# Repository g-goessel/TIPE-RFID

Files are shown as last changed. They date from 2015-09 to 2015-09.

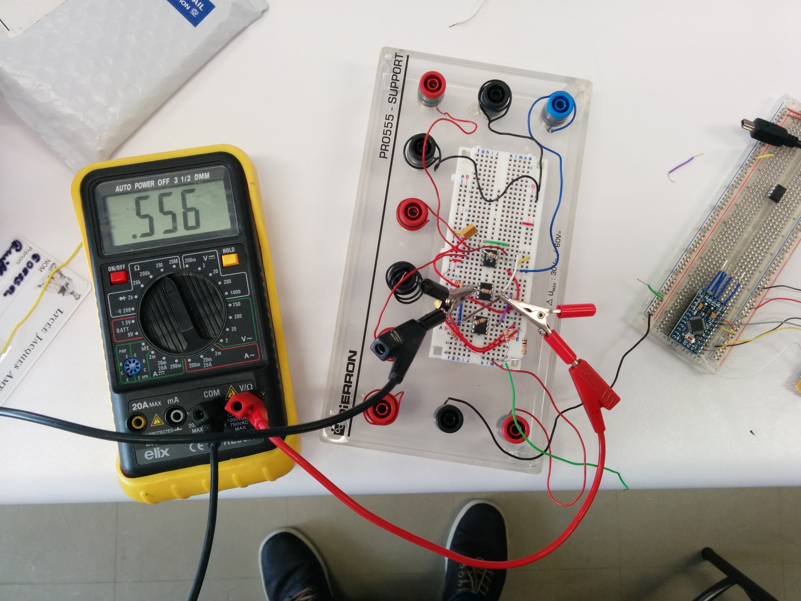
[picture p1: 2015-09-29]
Photos/IMG_20150519_115124.jpg

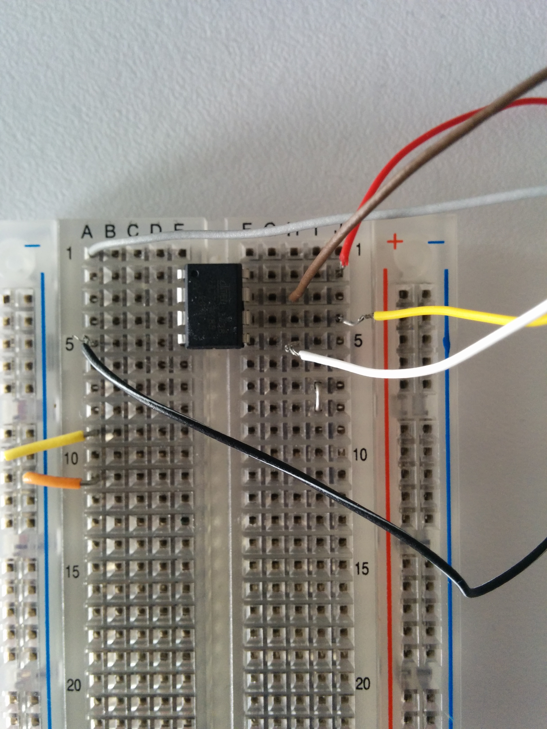
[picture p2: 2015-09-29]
Photos/IMG_20150522_102819.jpg

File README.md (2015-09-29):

# TIPE
Mon TIPE présenté en 2015

# Sujet
La RFID :
Comment les informations d'une carte RFID sont-elles réparties dans le message transmis au lecteur ?

# Schéma électronique
Il faut utiliser le logiciel Fritzing

# Aquisitions de signal
Logiciel Latis Pro (http://eurosmart.biz/logiciels/8-latis-pro.html)

# License
This Source Code Form is subject to the terms of the Mozilla Public
License, v. 2.0. If a copy of the MPL was not distributed with this
file, You can obtain one at http://mozilla.org/MPL/2.0/.

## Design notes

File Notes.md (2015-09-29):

# Mesure de champ électromagnétique à proximité d'un capteur

Calibre 5-400 kHz
A distance : 3.4 Vm
A proximité : 51 Vm

# Detection d'enveloppe VS détection asynchrone

Enveloppe : + simple

Asynchrone : + précis

# Analyse du protocole

On reconnait une répétition des signaux
Mais il ne smeble pas y avoir de signaux de début ou de fin (pas de temps de pause caractéristiques entre 2 répétitions)

protocole fdx-b:
http://www.priority1design.com.au/fdx-b_animal_identification_protocol.html

encoding :
http://www.priority1design.com.au/em4100_protocol.html

# période du signal

pour une fréquence de 134kHz on a une horloge de 237µs pour le signal

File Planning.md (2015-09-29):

# 3/10 :
Première expérience avec 2 bobines, un GDF réglé en sinusoïde à 125kHz
+ Impossible de lire un signal à l'oscillo
+ On remarque des variations dans le signal recu, il est un peu brouillé (car le signal recu n'est pas périodique)
+ Tentative avec un multiplicateur mais pas de resultats

Pour la semaine suivante : il va falloir mettre en place un système pour récupérer l'enveloppe

# 17/10 :
Tentative d'obtenir un signal clair
Succès d'obtention du signal modulant = message de la carte

# 14/11 :
Obtention des premiers signaux
Enregistrement de plusieurs cartes
Début de la reconnaissance du protocole

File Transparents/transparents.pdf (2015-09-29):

# La RFID :

## Comment les informations d'une carte RFID sont-elles réparties dans le message transmis au lecteur ?

# I – Introduction à la RFID et détails de ma carte

## - Utilisations courantes de la RFID - Détermination du protocole de ma carte

# II – Mise en place d'un lecteur automatique

## - Un circuit électronique pour lire - Un programme pour décoder

# Dénominations usuelles :

Nom commercial | Caractéristiques | Utilisation
NFC | 13,56 MHz | Paiement sans contact
| ≈ 1 cm | Cartes de transport
| ≈ 10 ko/s | authentification
| 125 kHz | Suivi de paquets
| ≈ 1 cm | Badges de paiement
| 100 o/s | Identification des animaux
| 8,2 MHz | Anti-vol

### Notes : - Différentes fréquences : pénétration / vitesse / disponibilité - Communication uni/bi-directionelle - Programmation à distance

# Analyse de ma carte :

## - Mesure approximative - Approche plus précise

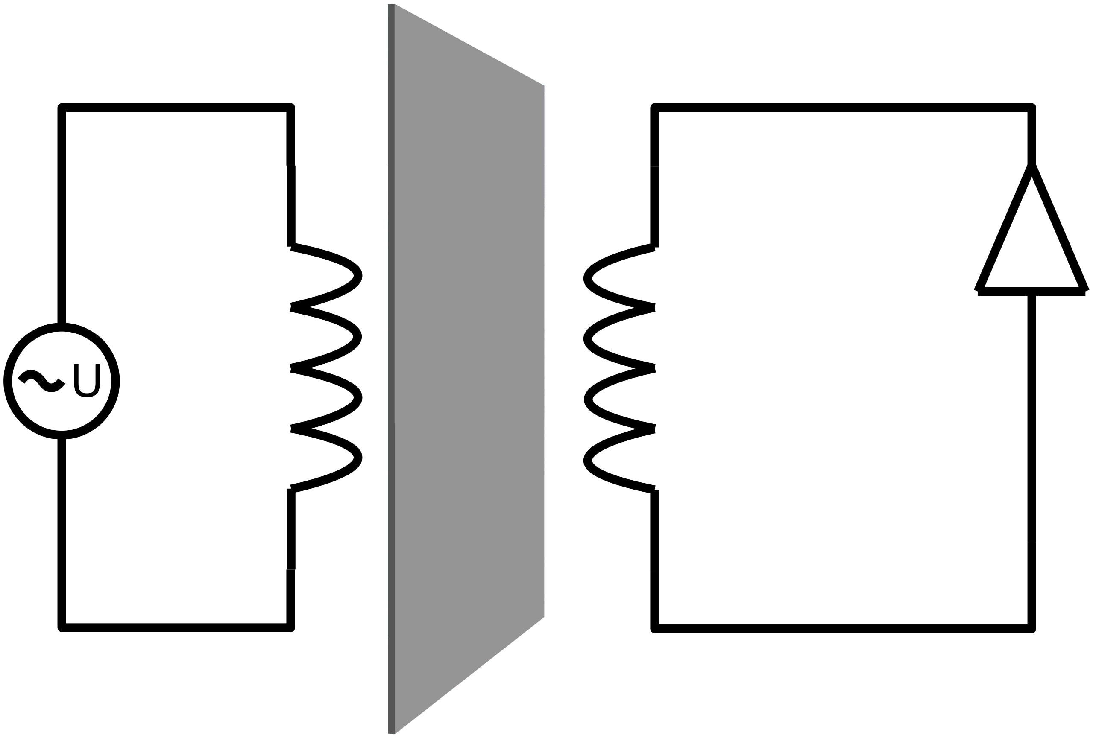
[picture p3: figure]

à 134kHZ :

≈ 100 mv

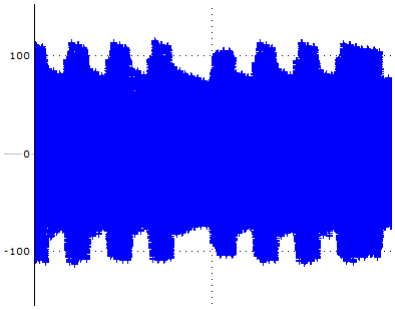
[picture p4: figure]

≈ 5 ms

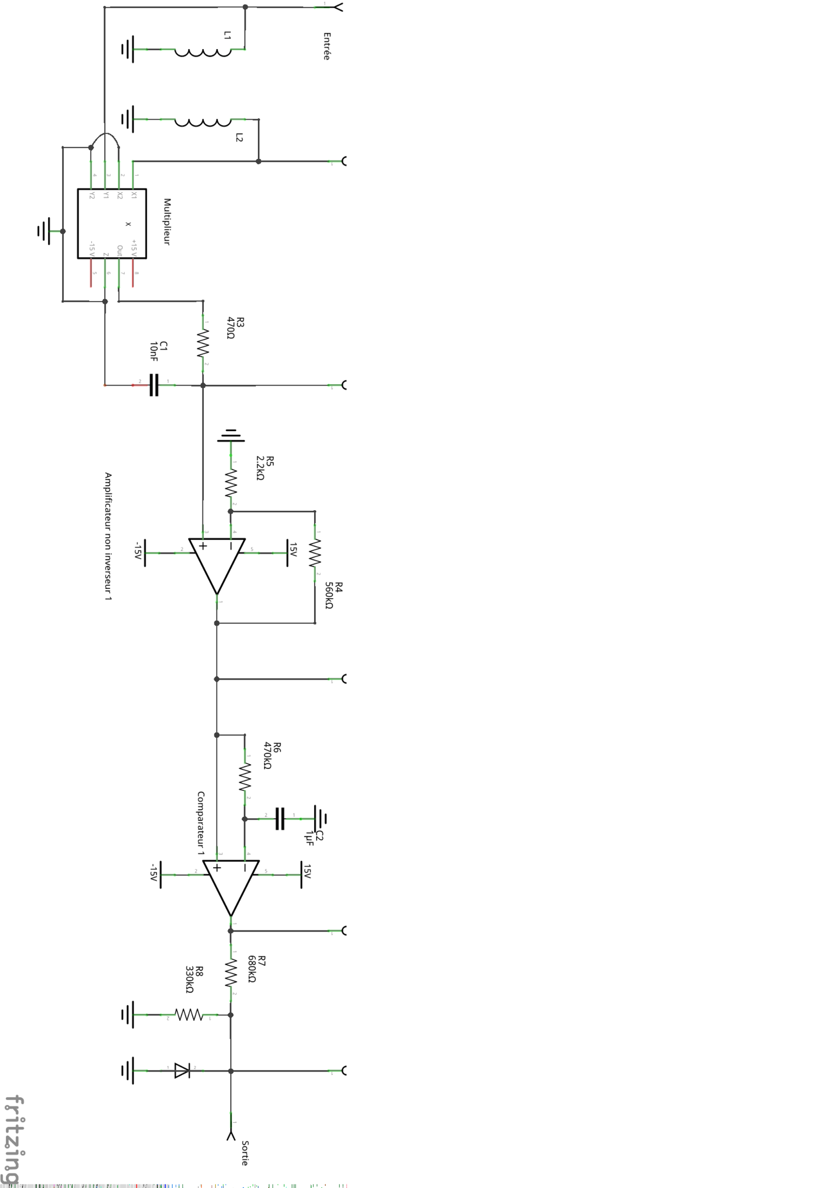
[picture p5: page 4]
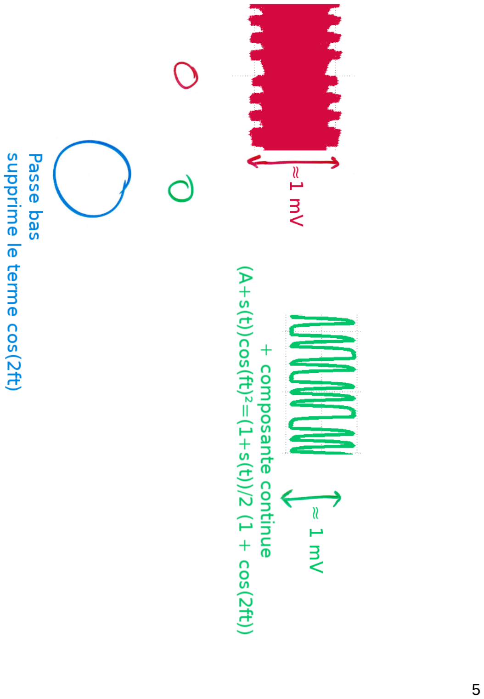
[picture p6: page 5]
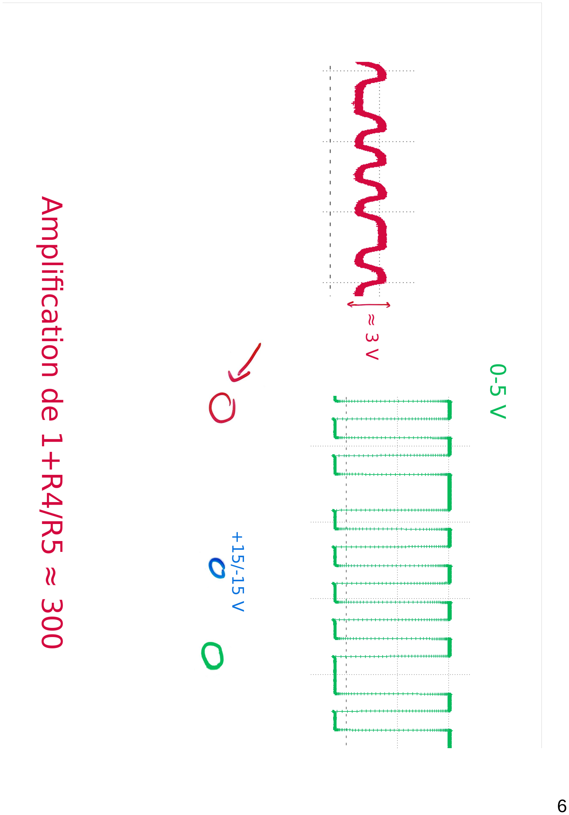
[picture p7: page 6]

# Détails du protocole de ma carte :

## - Codage en Manchester

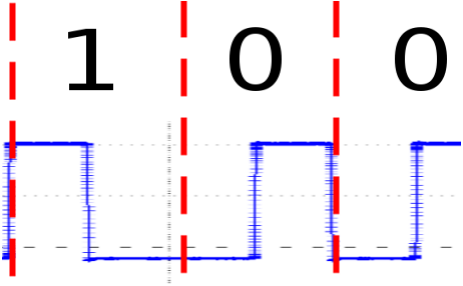
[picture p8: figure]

## Remarque : une impulsion longue indique un changement de bit

# Analyse de ma carte :

## - Première idée On effectue UNE seule mesure par période

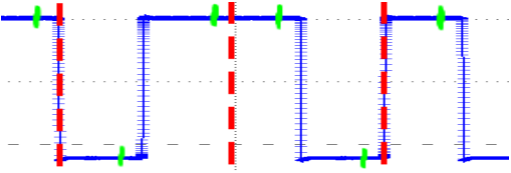
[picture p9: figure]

## Échec car peu précis

# Analyse de ma carte :

## - Seconde idée

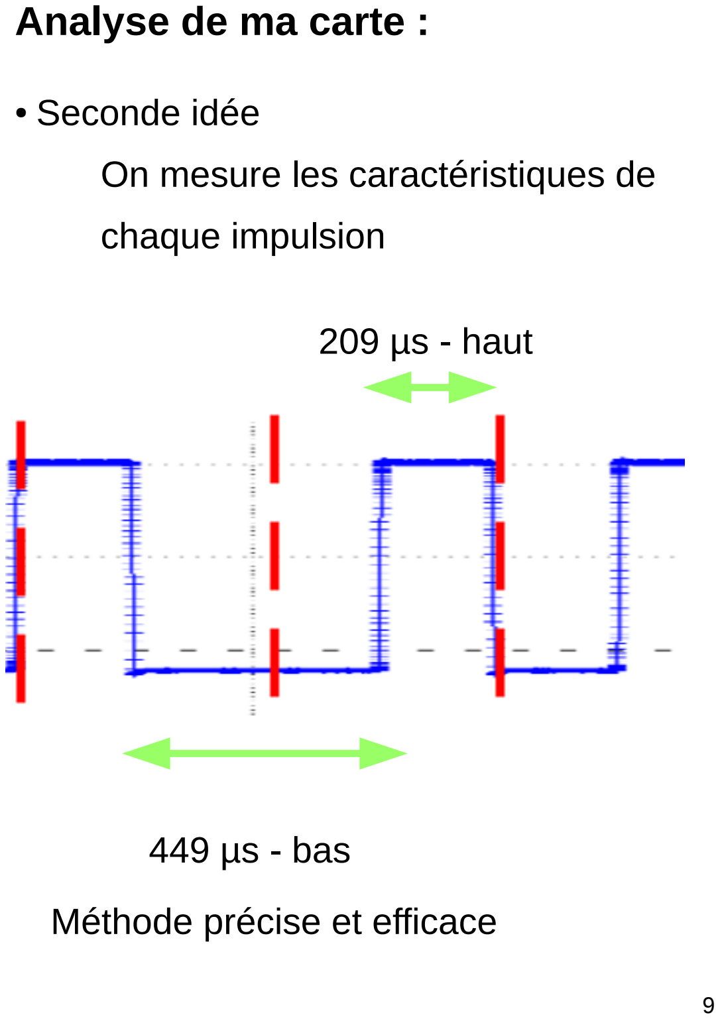
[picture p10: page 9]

## On mesure les caractéristiques de chaque impulsion

## 449 µs - bas

## 209 µs - haut

## Méthode précise et efficace

# Décodage par ordinateur :

## - Détail du protocole EM4100 (EM Microelectronic)

1 1 1 1 1 1 1 1 1
0 0 0 0 | 0
1 0 1 0 | 0
0 0 0 0 | 0
0 0 1 1 | 0
0 0 0 0 | 0
0 0 0 0 | 0
0 0 0 0 | 0
0 0 0 1 | 1
1 1 0 0 | 0
0 0 1 1 | 0
0 1 1 1 | 0

# Décodage par ordinateur :

## - Détail du programme 1) Distinguer impulsions longues et courtes

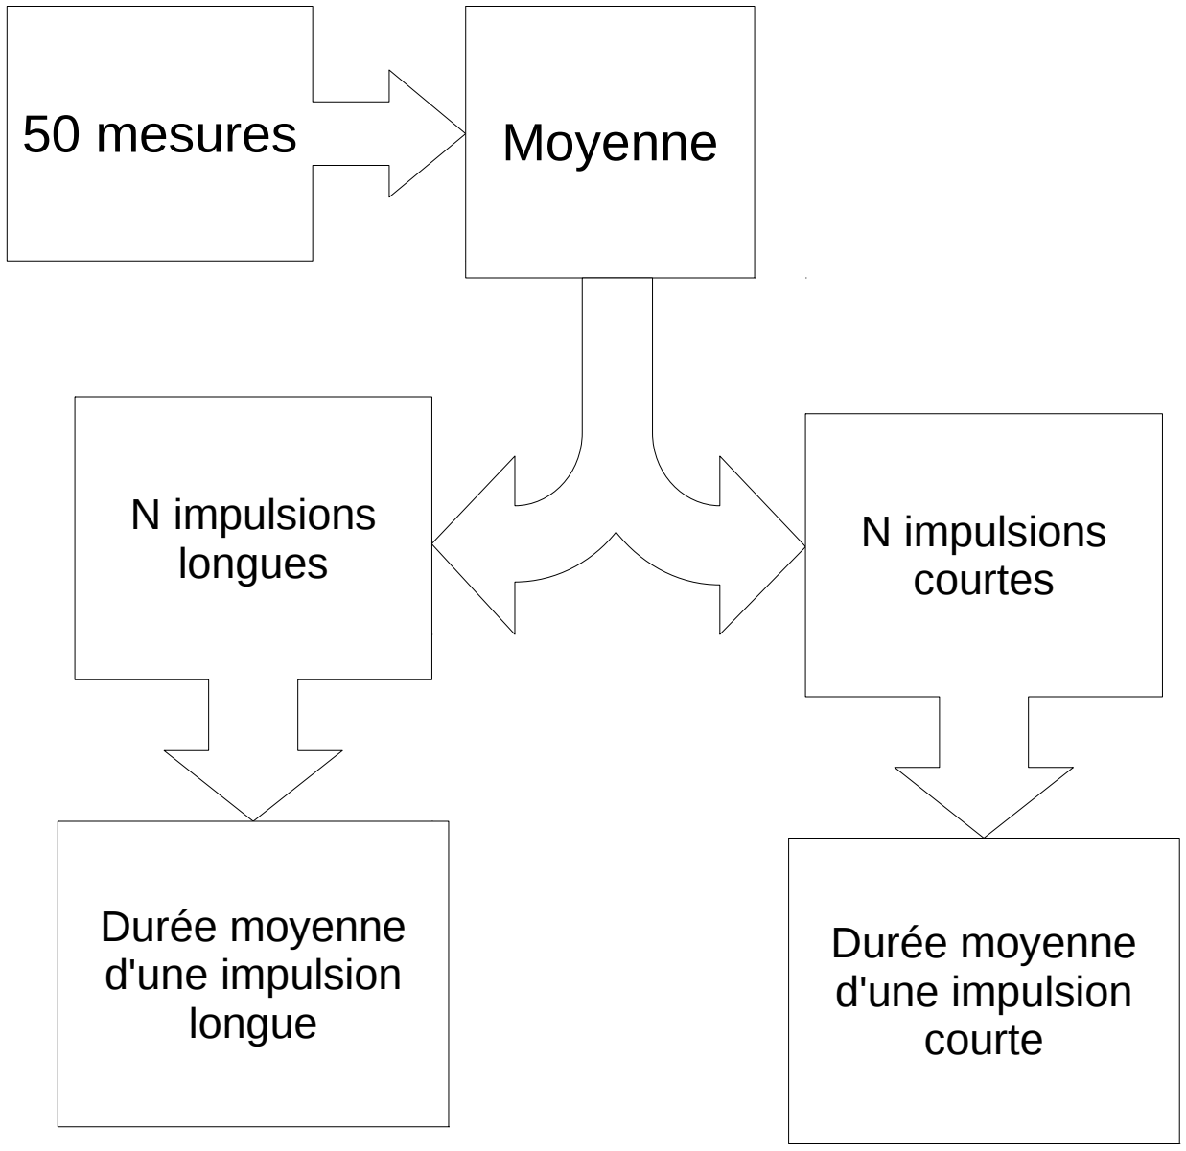
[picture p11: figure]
50 mesures; Moyenne; N impulsions longues; N impulsions courtes; Durée moyenne d'une impulsion longue; Durée moyenne d'une impulsion courte

### Ensuite on compare à la moyenne des deux durées

# Décodage par ordinateur :

## 2) Reconstituer les bits par récurrence a) Initialisation

0 1

# Décodage par ordinateur :

## b) Hérédité Cas ou le bit n est 0

bit n = 0 | bit n+1 = 1
bit n = 0 | bit n+1 = bit n

Impulsion longue

Impulsion courte

# Décodage par ordinateur :

## 3) Reconstituer le message

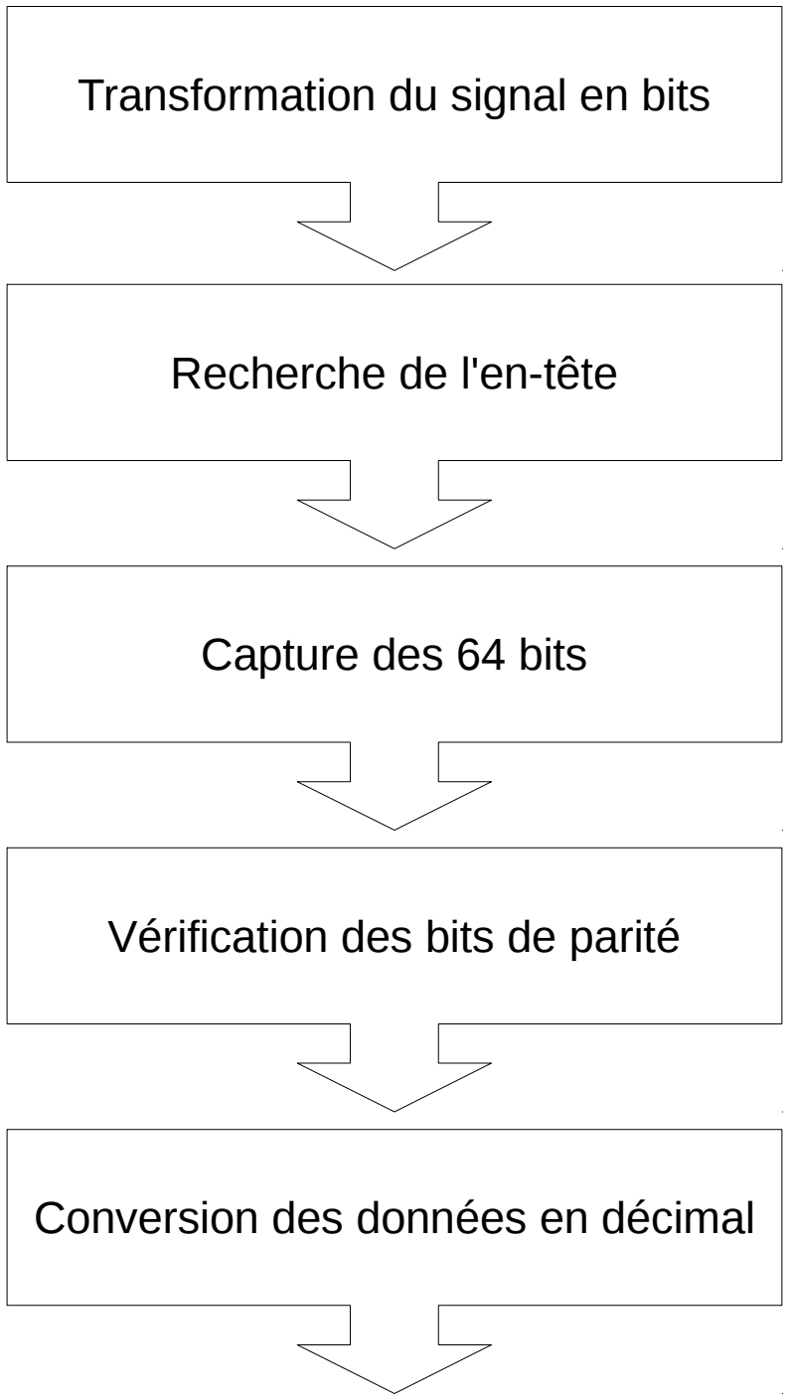
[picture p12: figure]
Recherche de l'en-tête; Capture des 64 bits; Conversion des données en décimal; Vérification des bits de parité; Transformation du signal en bits

43 00000 5059

# Bilan et conclusions :

## - Peu d'informations dans la carte - Aucune protection des données

# Reconstitution des bits :

def read(ser):
echantillon = []
ser.flushInput()
ser.readline()
for i in range(50):
duree = int(ser.readline().decode().replace("\r\n","")[2:]) echantillon.append(duree)
moy = mean(echantillon)
longs = [a for a in echantillon if a > moy]
courts = [a for a in echantillon if a < moy] court = mean(courts)
long = mean(longs)
moy = mean([court,long])
#-------------------------------------------------------------------------bits=[]

message = ser.readline().decode().replace("\r\n","") while message[0] != 'l' or int(message[2:]) < moy: message = ser.readline().decode().replace("\r\n","") # On a alors un 1
Bits+=[1,0]
# ---------------------------------------------------------------------------# On va ensuite décoder les 200 bits suivants

for i in range(200):
print(i)
duree = int(ser.readline().decode().replace("\r\n","")[2:]) last = bits[-1]
if duree > moy:
# On a une pulsation longue donc on passe au bit opposé

bits.append(int(not last))
else :
# On a une pulsation courte donc on conserve le même bit

bits.append(last)
ser.readline()
return bits

Evaluation des
durées des
impulsions

Initialisation

Récurrence

## La fonction retourne une liste contenant environ 200 bits

# Décodage :

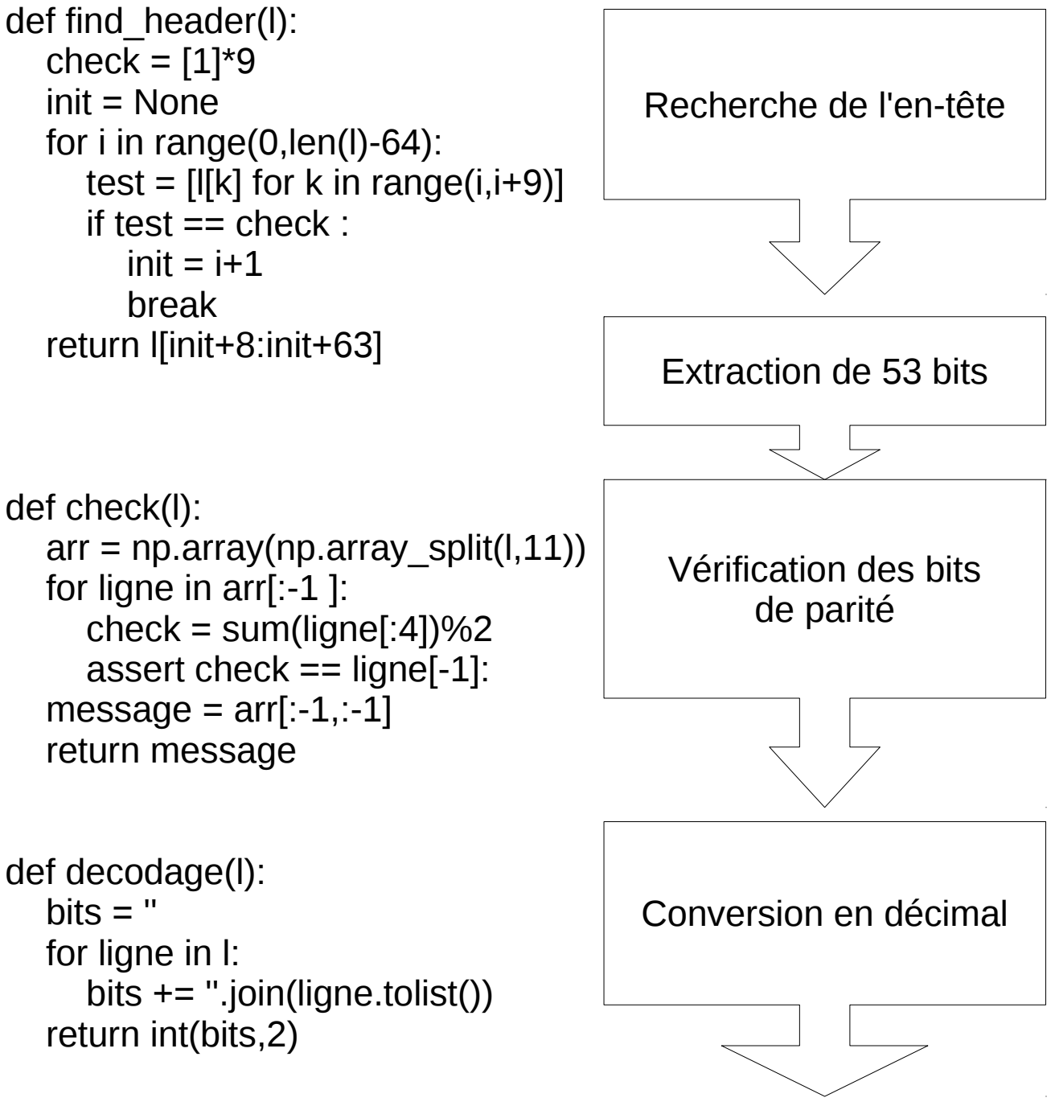
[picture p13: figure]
def find_header(l): check = [1]*9 init = None for i in range(0,len(l)-64): test = [l[k] for k in range(i,i+9)] if test == check : init = i+1 break return l[init+8:init+63]; def check(l): arr = np.array(np.array_split(l,11)) for ligne in arr[:-1 ]: check = sum(ligne[:4])%2 assert check == ligne[-1]: message = arr[:-1,:-1] return message; def decodage(l): bits = '' for ligne in l: bits += ''.join(ligne.tolist()) return int(bits,2); Recherche de l'en-tête; Extraction de 53 bits; Conversion en décimal; Vérification des bits de parité

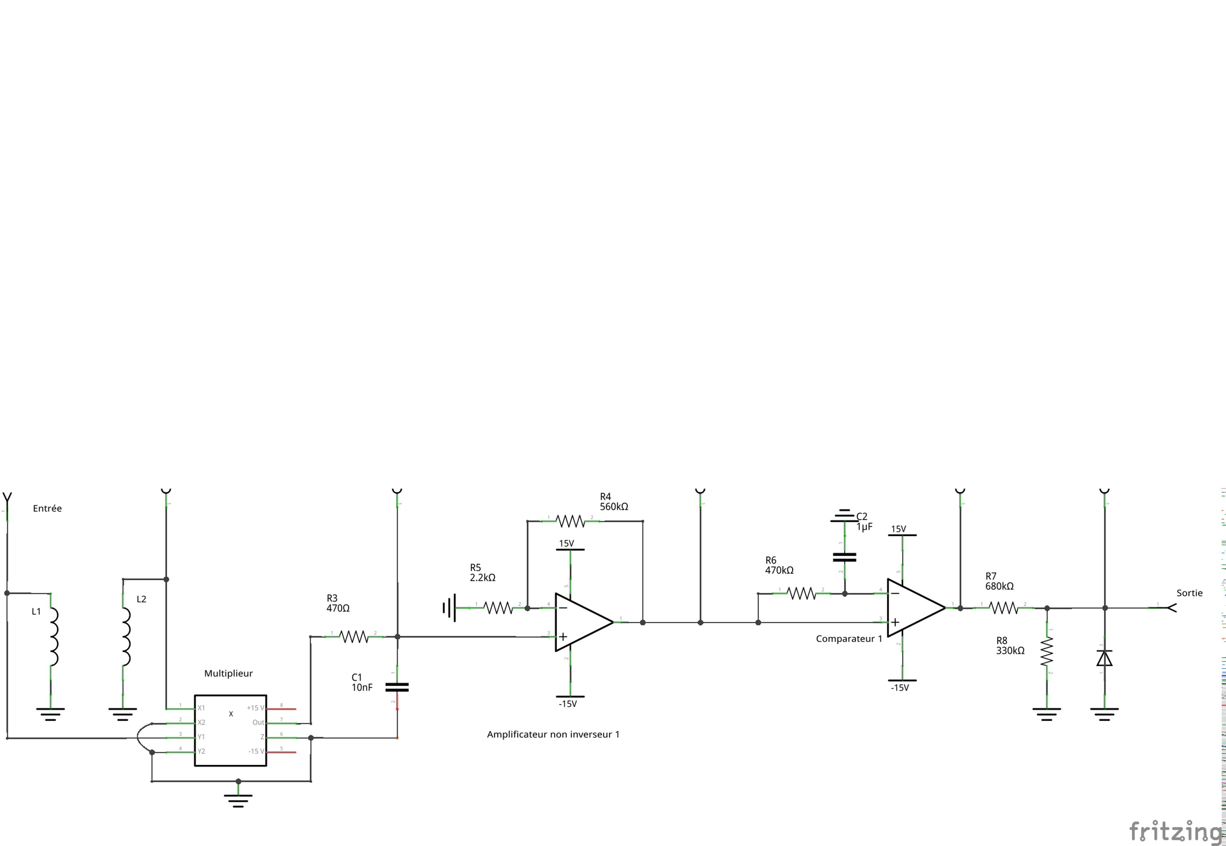
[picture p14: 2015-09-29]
Circuit_schéma.png

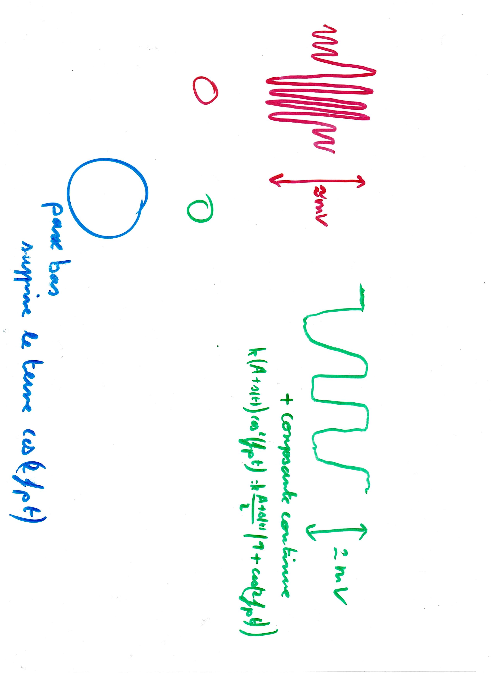
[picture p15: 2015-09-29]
Transparents/Document numérisé-04.jpg

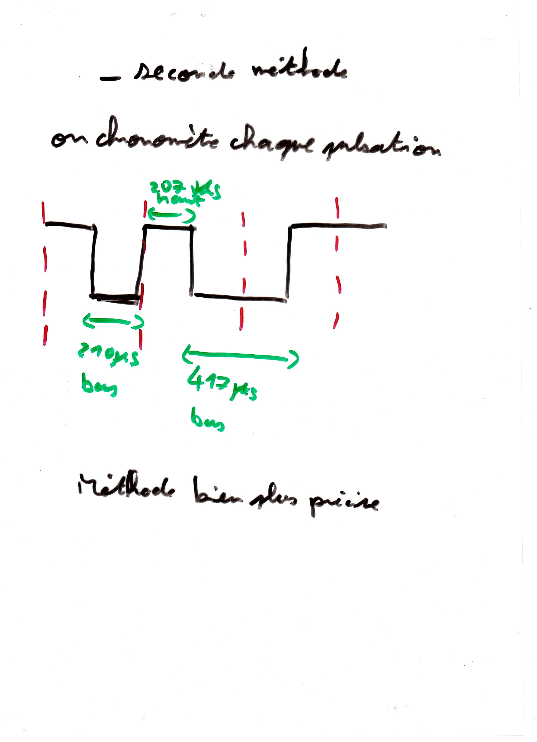
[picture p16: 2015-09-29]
Transparents/Document numérisé-07.jpg

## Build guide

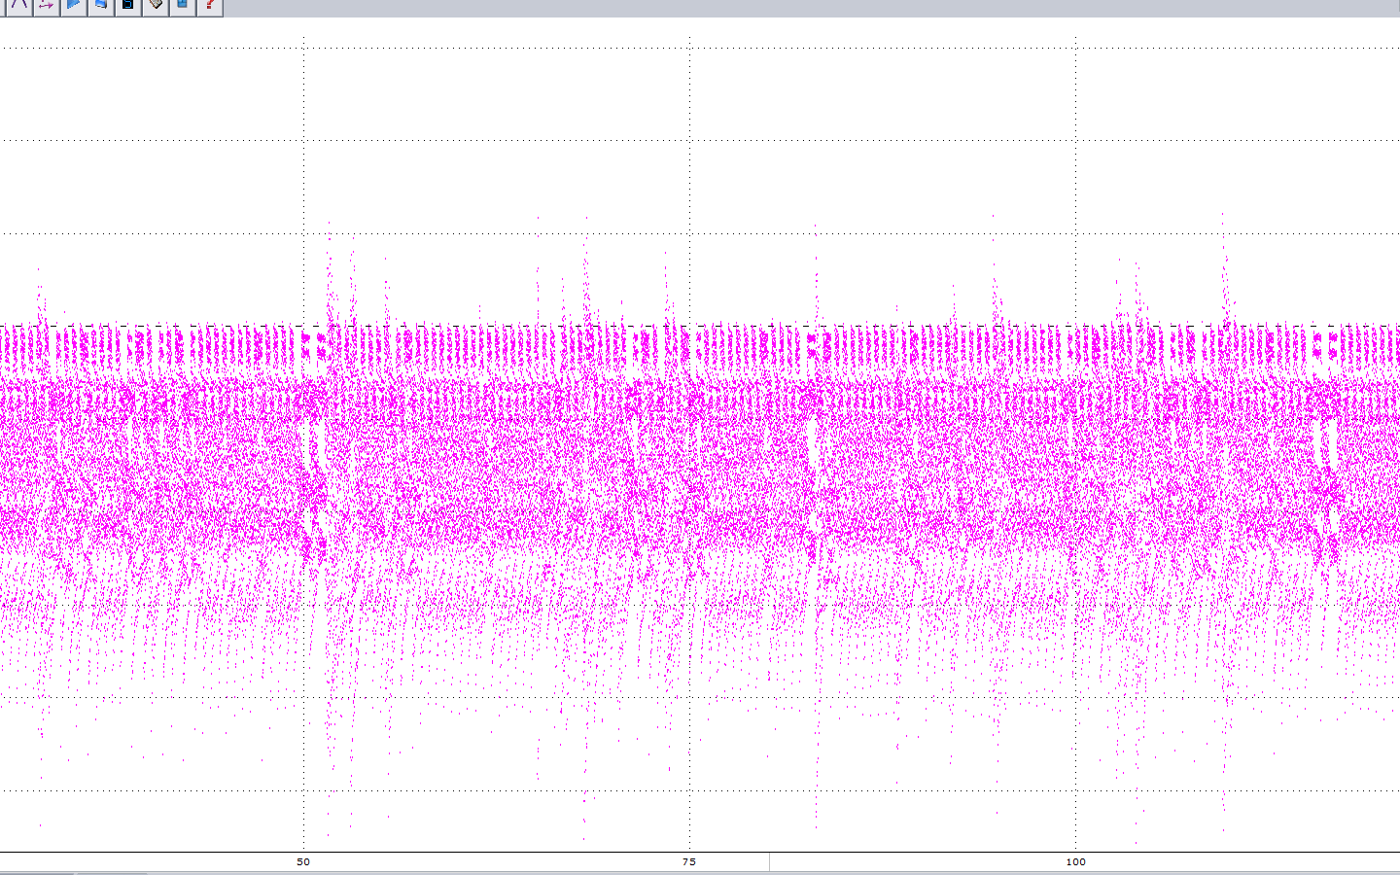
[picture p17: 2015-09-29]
acquisitions/montage.png

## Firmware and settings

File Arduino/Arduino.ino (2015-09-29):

volatile unsigned long high,low;

void setup()
{
    Serial.begin(115200);
    Serial.println("hello world!");
    high = 0;
    low = 0;
    //pinMode(3,OUTPUT);
    //digitalWrite(3,HIGH); // Pull-up
    attachInterrupt(0, interrupt_high, FALLING); //Interrupt sur D2
    attachInterrupt(1, interrupt_low, RISING); //Interrupt sur D3
}

void loop()
{
}

void interrupt_high()
{
    high=micros();
    //Serial.print("h ");
    Serial.println(high-low);
}

void interrupt_low()
{
    low = micros();
    //Serial.print("l ");
    Serial.println(low-high);
}

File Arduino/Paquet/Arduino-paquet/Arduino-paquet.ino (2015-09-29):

//Ici la lecture depuis le µc se fait par "paquets" de 300 impulsions
volatile long high,low,count;
volatile long data[301];

void setup()
{
    Serial.begin(115200);
    Serial.println("start");
    high = 0;
    low = 0;
    //pinMode(3,OUTPUT);
    //digitalWrite(3,HIGH); // Pull-up


    // on déclare les interrupts
    attachInterrupt(0, interrupt_high, FALLING); //Interrupt sur D2
    attachInterrupt(1, interrupt_low, RISING); //Interrupt sur D3
}

void loop()
{
  if (count > 300)
  {
    noInterrupts();
    for (int i=0;i< 300;i++)
    {
      Serial.println(data[i]);
    }
    count = 0;
    high=micros();
    low=high;
    interrupts();
  }
}

void interrupt_high()
{
    high=micros();
    if(count == 0)
    {
      data[0] = 0;
      count ++;
    }
    if (count <= 300)
    {
      data[count] =  high-low;
      count ++;
    }
}

void interrupt_low()
{
    low = micros();
    if(count == 0)
    {
      data[0] = 1;
      count ++;
    }
    if(count <= 300)
    {
      data[count] = low-high;
      count ++;
    }

}
